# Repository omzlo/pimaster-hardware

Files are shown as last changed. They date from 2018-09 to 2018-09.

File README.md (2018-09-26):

# PiMaster HAT Hardware

This repository contains the design files and schematics of the Omzlo PiMaster HAT (Hardware Attached on Top).

See: http://omzlo.com/pimaster

This work is licensed under the [Creative Commons Attribution-ShareAlike 4.0 International Public License][1].

[1]: https://creativecommons.org/licenses/by-sa/4.0/

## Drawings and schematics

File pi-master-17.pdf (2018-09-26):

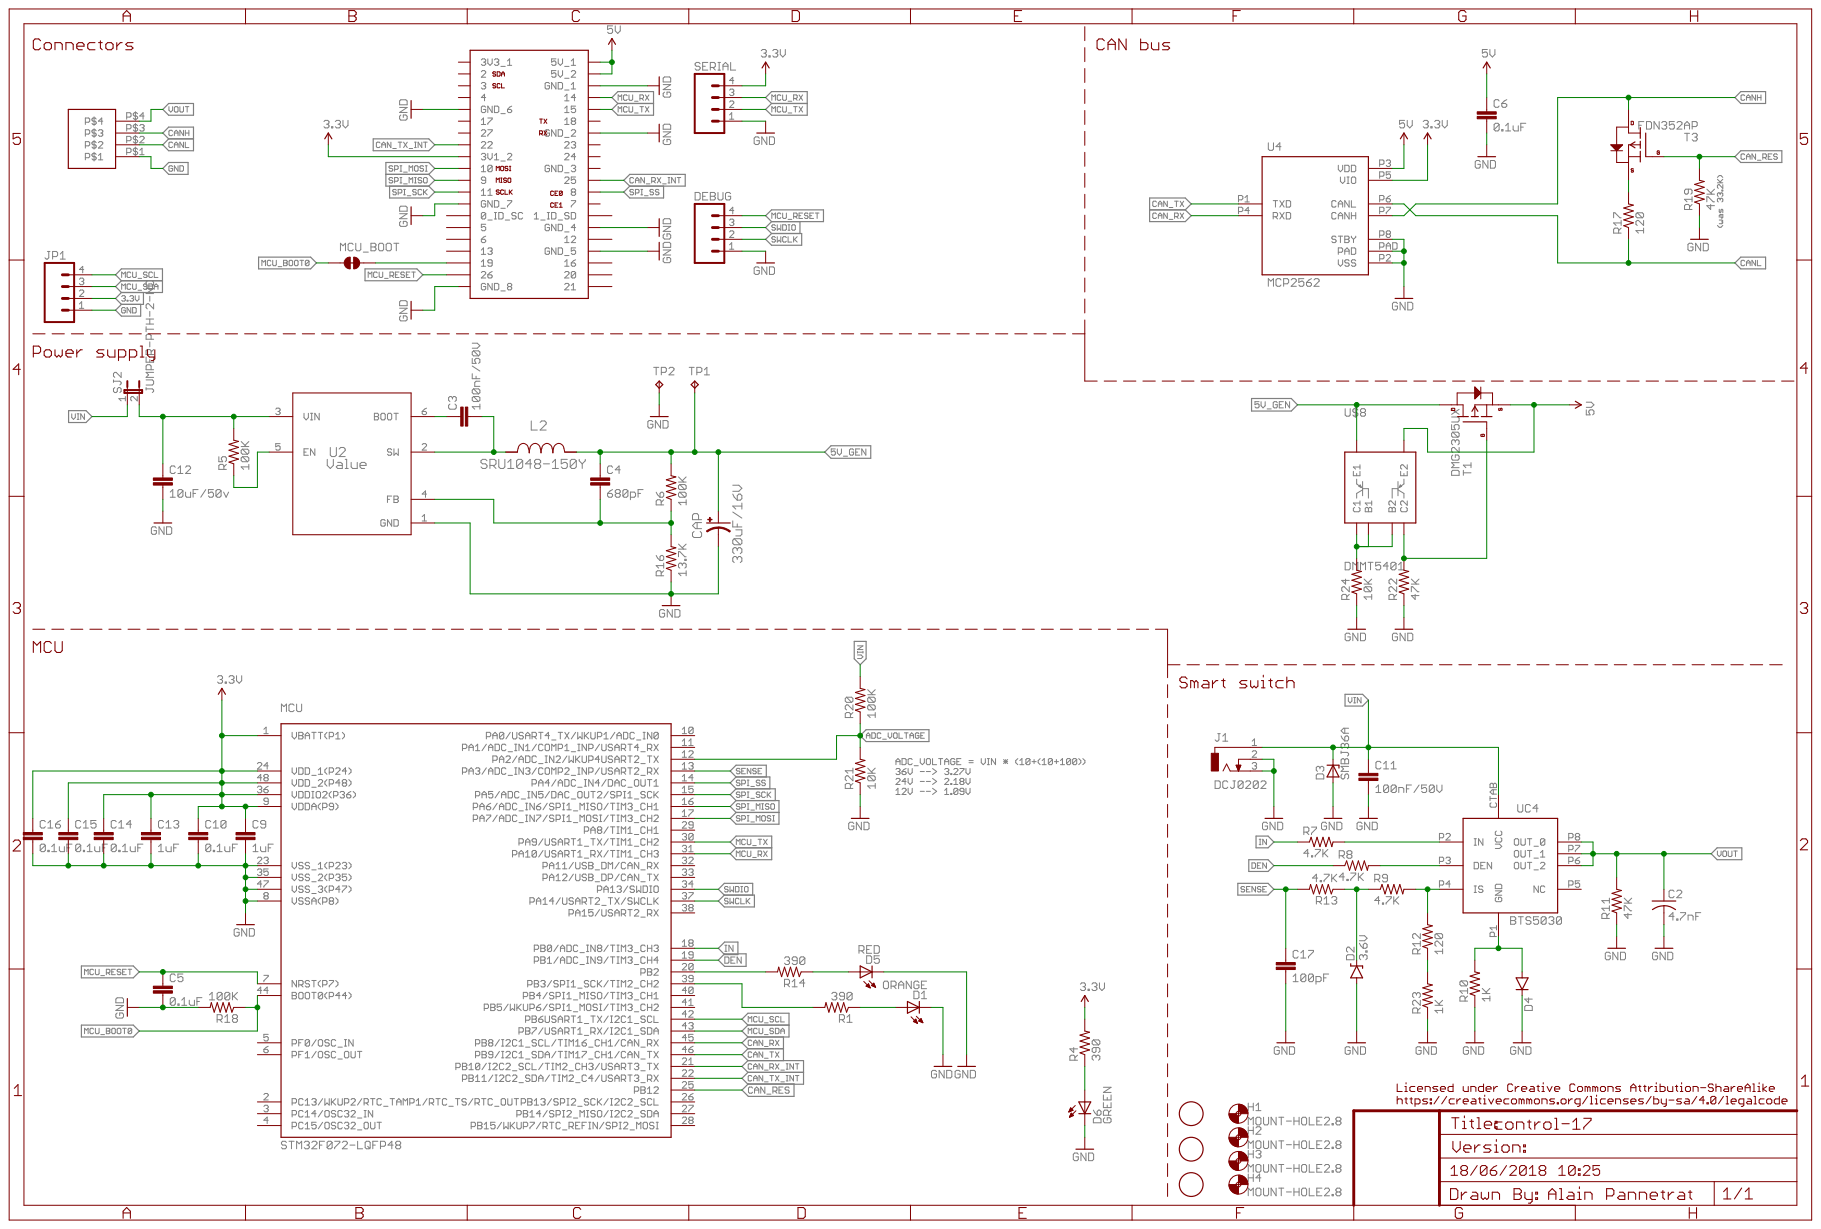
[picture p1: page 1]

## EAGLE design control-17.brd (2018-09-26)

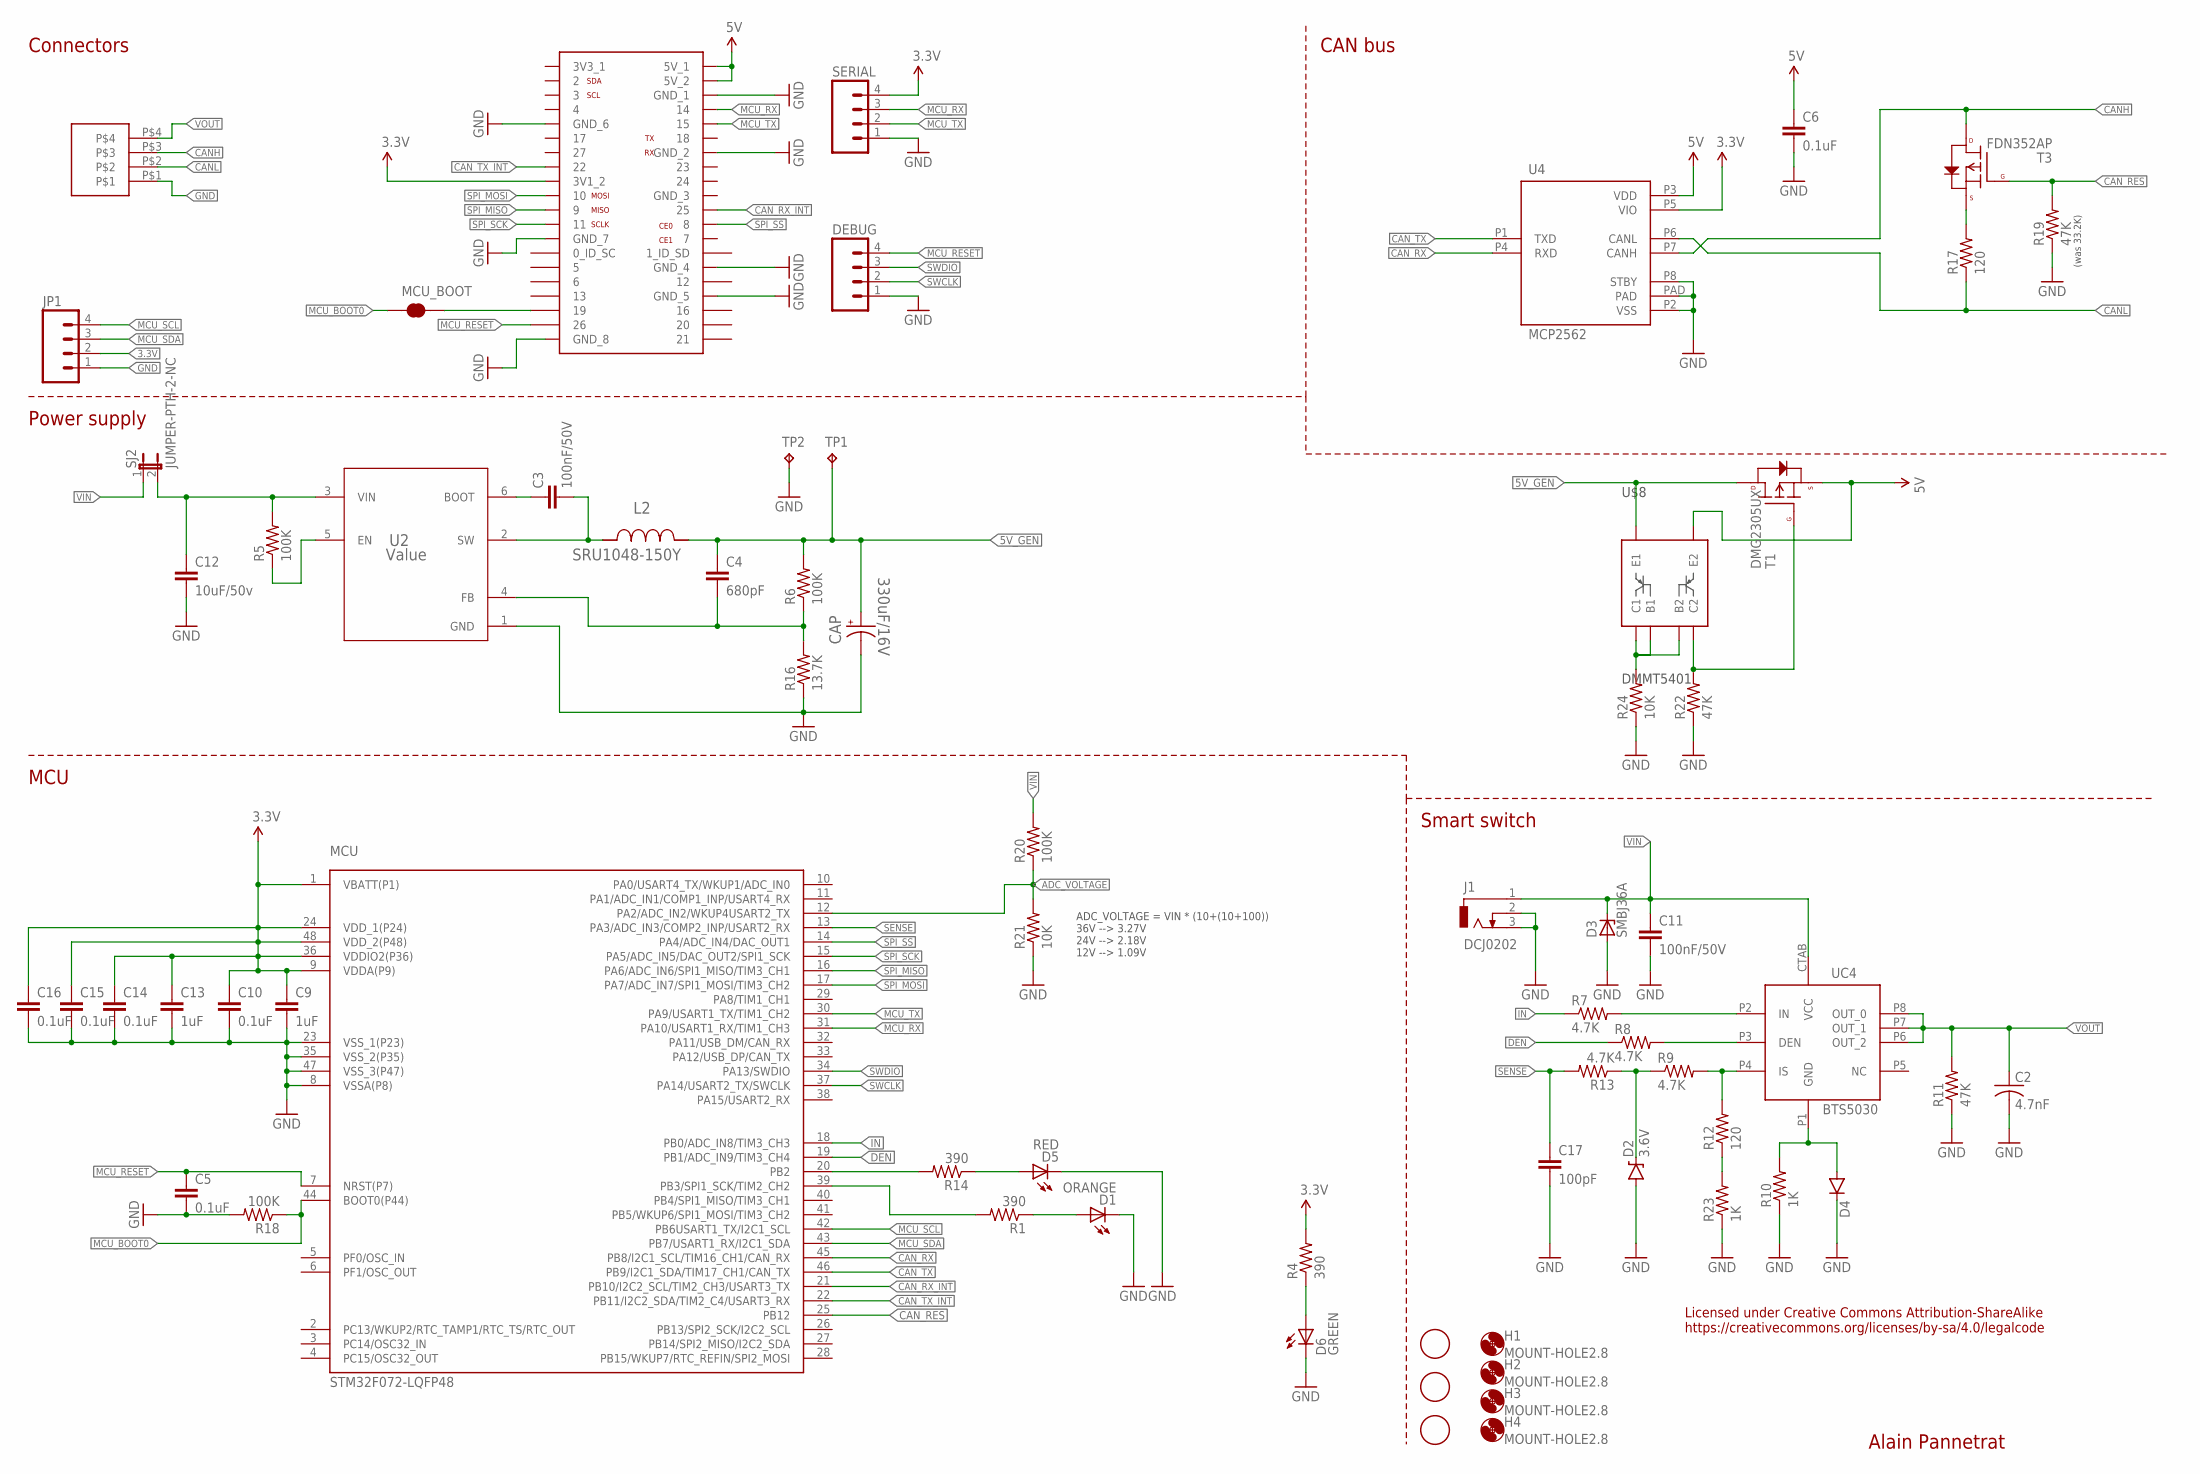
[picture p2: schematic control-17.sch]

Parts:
C2: 4.7nF; C0805
C3, C11: 100nF/50V; 0805
C4: 680pF; 0603-CAP
C5, C6, C10, C14, C15, C16: 0.1uF; 0603-CAP
C9, C13: 1uF; 0805
C12: 10uF/50v; 1206
C17: 100pF; 0805
CAP: 330uF/16V; PANASONIC_E
D1: ORANGE; CHIPLED_0805
D2: 3.6V; SOD-323
D3: SMBJ36A; SMB
D4: DIODESMA; SMA-DIODE
D5: RED; CHIPLED_0805
D6: GREEN; CHIPLED_0805
DEBUG: M04PTH; 1X04
H1, H2, H3, H4: MOUNT-HOLE2.8; 2,8
J1: DCJ0202
JP1: M04JST; 1X04-1.5MM_JST
L2: SRU1048-150Y; SRU1048
MCU: STM32F072-LQFP48; LQFP48
MCU_BOOT: JUMPER-PAD-2-NC_BY_TRACE; PAD-JUMPER-2-NC_BY_TRACE_YES_SILK
PI: RASPBERRY-PI-GPIO-SEPARATE; 2X20
R1, R4, R14: 390; R0603
R5, R6, R18, R20: 100K; R0603
R7, R8, R9, R13: 4.7K; R0805
R10, R23: 1K; R0805
R11, R19, R22: 47K; R0805
R12, R17: 120; R0805
R16: 13.7K; R0805
R21, R24: 10K; R0805
SERIAL: M04PTH; 1X04
SJ2: JUMPER-PTH-2-NC; PTH-JUMPER-NC_BOTTOM_NO_SILK
T1: DMG2305UX; SOT23-3
T3: FDN352AP; SOT23-3
TP1, TP2: TPPAD1-13; P1-13
U2: Value; DDC0006A_N
U4: MCP2562; DFN3X3
U$3: M04-PLUG-3.5
U$4, U$5, U$6: FIDUCIAL; FIDUCIAL_1MM
U$8: DMMT5401; SOT-23-6
UC4: BTS5030; PG-DSO-8-43

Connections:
3.3V: C9.1, C10.1, C13.1, C14.1, C15.1, C16.1, JP1.2, MCU.1 (VBATT(P1)), MCU.9 (VDDA(P9)), MCU.24 (VDD_1(P24)), MCU.36 (VDDIO2(P36)), MCU.48 (VDD_2(P48)), PI.17 (3V1_2), R4.2, SERIAL.4, U4.P5 (VIO)
3V3_1: PI.1 (3V3_1)
5V: C6.1, PI.2 (5V_1), PI.4 (5V_2), T1.2 (S), U4.P3 (VDD), U$8.5 (E2)
5V_GEN: C4.1, CAP.+, L2.2, R6.2, T1.3 (D), TP1.TP, U$8.6 (E1)
ADC_VOLTAGE: MCU.12 (PA2/ADC_IN2/WKUP4USART2_TX), R20.1, R21.2
CANH: T3.3 (D), U4.P7 (CANH), U$3.P$3
CANL: R17.1, U4.P6 (CANL), U$3.P$2
CAN_RES: MCU.25 (PB12), R19.2, T3.1 (G)
CAN_RX: MCU.45 (PB8/I2C1_SCL/TIM16_CH1/CAN_RX), U4.P4 (RXD)
CAN_RX_INT: MCU.21 (PB10/I2C2_SCL/TIM2_CH3/USART3_TX), PI.22 (25)
CAN_TX: MCU.46 (PB9/I2C1_SDA/TIM17_CH1/CAN_TX), U4.P1 (TXD)
CAN_TX_INT: MCU.22 (PB11/I2C2_SDA/TIM2_C4/USART3_RX), PI.15 (22)
DEN: MCU.19 (PB1/ADC_IN9/TIM3_CH4), R8.1
GND: C2.2, C5.2, C6.2, C9.2, C10.2, C11.2, C12.2, C13.2, C14.2, C15.2, C16.2, C17.2, CAP.-, D1.C, D2.A, D3.A, D4.C, D5.C, D6.C, DEBUG.1, J1.2, J1.3, JP1.1, MCU.8 (VSSA(P8)), MCU.23 (VSS_1(P23)), MCU.35 (VSS_2(P35)), MCU.47 (VSS_3(P47)), PI.6 (GND_1), PI.9 (GND_6), PI.14 (GND_2), PI.25 (GND_7), PI.30 (GND_4), PI.34 (GND_5), PI.39 (GND_8), R10.1, R11.1, R16.1, R18.2, R19.1, R21.1, R22.1, R23.1, R24.1, SERIAL.1, TP2.TP, U2.1 (GND), U4.P2 (VSS), U4.P8 (STBY), U4.PAD, U$3.P$1
IN: MCU.18 (PB0/ADC_IN8/TIM3_CH3), R7.1
MCU_BOOT0: MCU.44 (BOOT0(P44)), MCU_BOOT.1, R18.1
MCU_RESET: C5.1, DEBUG.4, MCU.7 (NRST(P7)), PI.37 (26)
MCU_RX: MCU.31 (PA10/USART1_RX/TIM1_CH3), PI.8 (14), SERIAL.3
MCU_SCL: JP1.4, MCU.42 (PB6USART1_TX/I2C1_SCL)
MCU_SDA: JP1.3, MCU.43 (PB7/USART1_RX/I2C1_SDA)
MCU_TX: MCU.30 (PA9/USART1_TX/TIM1_CH2), PI.10 (15), SERIAL.2
unnamed: D2.C, R9.1, R13.1
unnamed: D1.A, R1.1
unnamed: R7.2, UC4.P2 (IN)
unnamed: MCU_BOOT.2, PI.35 (19)
unnamed: R5.1, U2.5 (EN)
unnamed: C12.1, R5.2, SJ2.2, U2.3 (VIN)
unnamed: C4.2, R6.1, R16.2, U2.4 (FB)
unnamed: R12.1, R23.2
unnamed: R8.2, UC4.P3 (DEN)
unnamed: MCU.20 (PB2), R14.2
unnamed: R17.2, T3.2 (S)
unnamed: R9.2, R12.2, UC4.P4 (IS)
unnamed: D4.A, R10.2, UC4.P1 (GND)
unnamed: MCU.39 (PB3/SPI1_SCK/TIM2_CH2), R1.2
unnamed: C3.2, L2.1, U2.2 (SW)
unnamed: D5.A, R14.1
unnamed: C3.1, U2.6 (BOOT)
unnamed: D6.A, R4.1
unnamed: R24.2, U$8.1 (C1), U$8.2 (B1), U$8.3 (B2)
unnamed: R22.2, T1.1 (G), U$8.4 (C2)
SENSE: C17.1, MCU.13 (PA3/ADC_IN3/COMP2_INP/USART2_RX), R13.2
SPI_MISO: MCU.16 (PA6/ADC_IN6/SPI1_MISO/TIM3_CH1), PI.21 (9)
SPI_MOSI: MCU.17 (PA7/ADC_IN7/SPI1_MOSI/TIM3_CH2), PI.19 (10)
SPI_SCK: MCU.15 (PA5/ADC_IN5/DAC_OUT2/SPI1_SCK), PI.23 (11)
SPI_SS: MCU.14 (PA4/ADC_IN4/DAC_OUT1), PI.24 (8)
SWCLK: DEBUG.2, MCU.37 (PA14/USART2_TX/SWCLK)
SWDIO: DEBUG.3, MCU.34 (PA13/SWDIO)
VIN: C11.1, D3.C, J1.1, R20.2, SJ2.1, UC4.CTAB (VCC)
VOUT: C2.1, R11.2, U$3.P$4, UC4.P6 (OUT_2), UC4.P7 (OUT_1), UC4.P8 (OUT_0)

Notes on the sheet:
Alain Pannetrat
ADC_VOLTAGE = VIN * (10+(10+100)) 36V --> 3.27V 24V --> 2.18V 12V --> 1.09V
(was 33.2K)
Power supply
MCU
Smart switch
CAN bus
Connectors
Licensed under Creative Commons Attribution-ShareAlike https://creativecommons.org/licenses/by-sa/4.0/legalcode

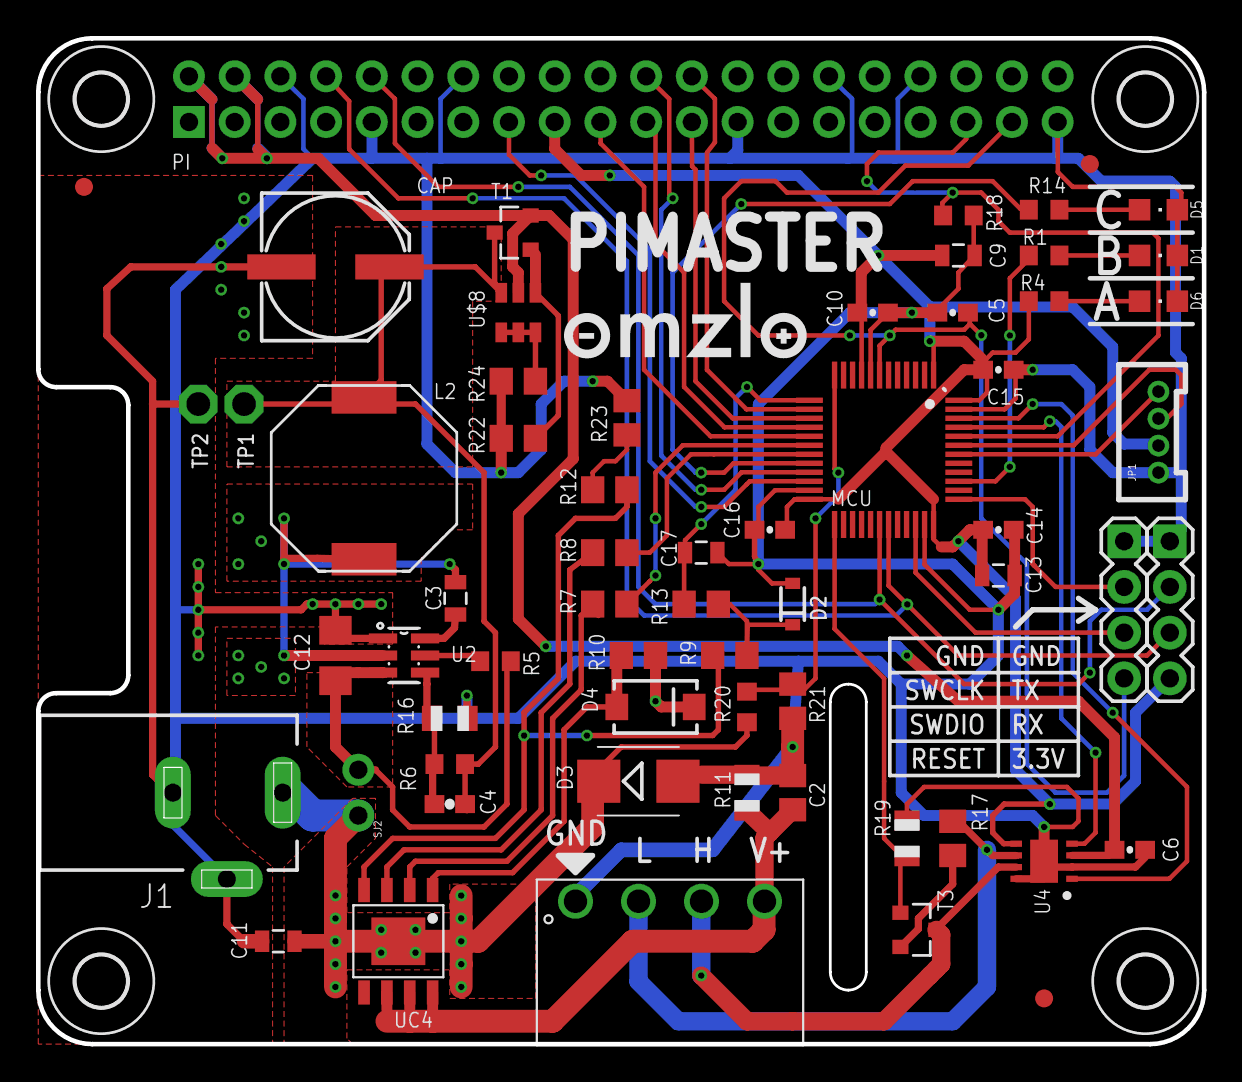
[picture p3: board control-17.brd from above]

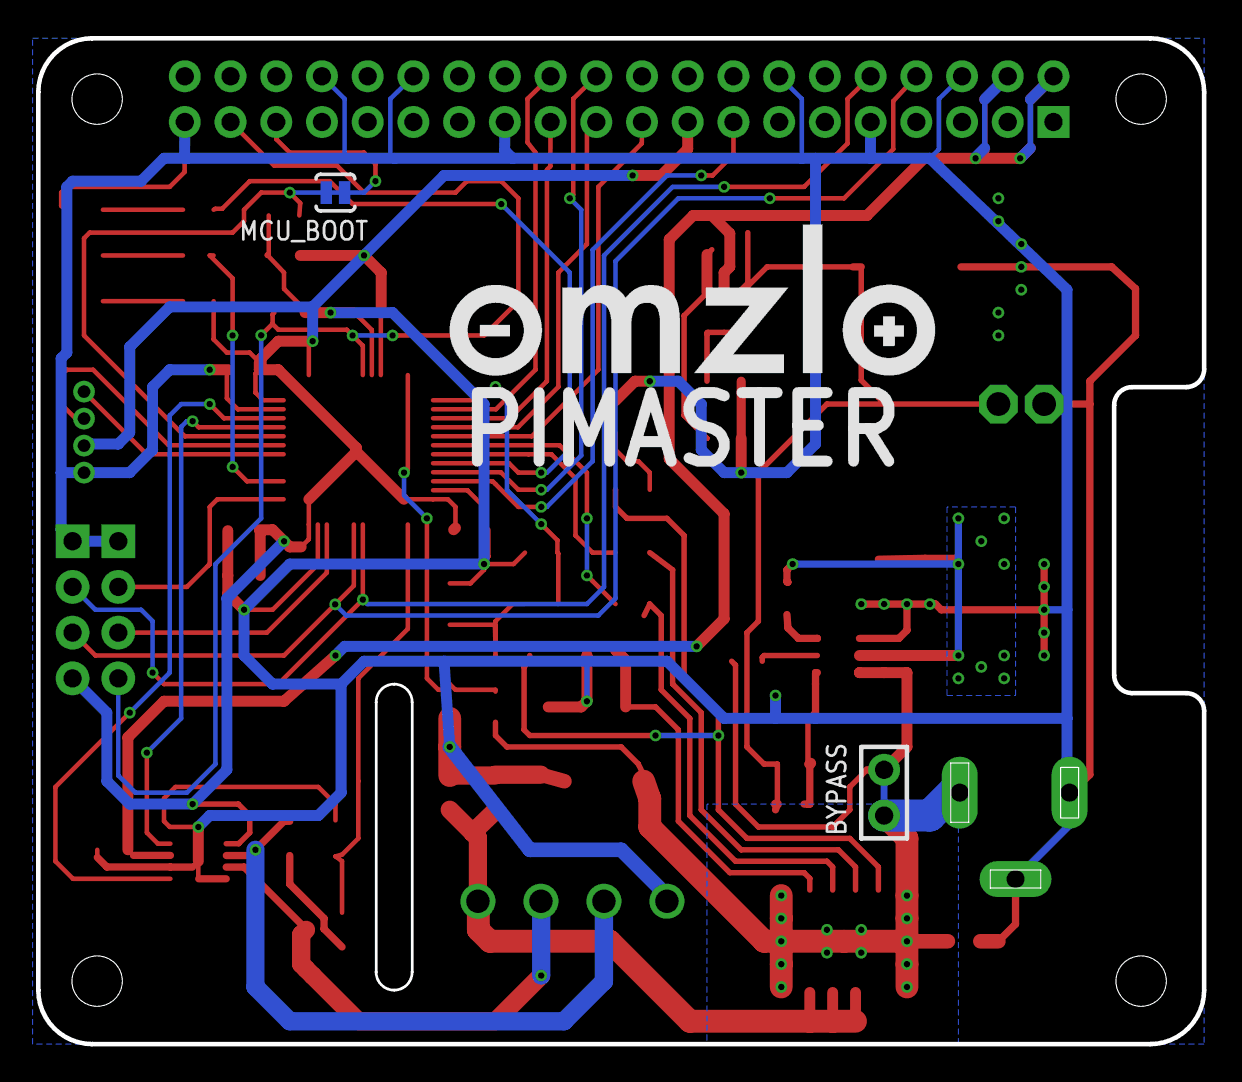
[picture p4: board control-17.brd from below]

Board: 2 copper layers, 64.8 x 55.9 mm, 69 parts (2 on the bottom side), 49 nets.

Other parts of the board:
U$1: OMZLO-0.5
U$2: OMZLO

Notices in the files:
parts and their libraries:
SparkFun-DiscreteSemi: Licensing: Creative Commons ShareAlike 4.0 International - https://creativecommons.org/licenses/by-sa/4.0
